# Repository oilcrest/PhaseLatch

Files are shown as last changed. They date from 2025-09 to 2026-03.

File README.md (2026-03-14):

# PhaseLatch

PhaseLatch – 6502-Interfaced High-Speed ADC for Experimental SDR

PhaseLatch is an open-source hardware project that explores how far a classic MOS 6502-class CPU can be pushed into modern signal-processing territory. The board implements a dual-channel, 10-bit, 20 MSPS analog-to-digital converter with a straight binary parallel output, allowing the ADC to be memory-mapped directly onto a 6502 (8 bit) data bus.

Unlike typical SDR designs that rely on high-performance microcontrollers or FPGAs, PhaseLatch intentionally interfaces high-speed conversion hardware with a severely resource-constrained 8-bit CPU. This makes it a platform for experimenting with timing limits, bus contention, memory expansion, and minimalist DSP techniques such as Goertzel tone detection executed entirely on the 6502.

The board is designed as a modular Arduino-shield-style form factor and is intended to stack with the PhaseLoom IQ mixer and the 65uino 6502 system. Direct access to the CPU address, data, and control signals enables single-instruction ADC reads and deterministic sampling under software control.

PhaseLatch is not intended to achieve full theoretical ADC bandwidth on a 6502. Instead, it serves as a practical exploration of real-world limitations, architectural trade-offs, and creative signal-processing approaches on vintage computing hardware.

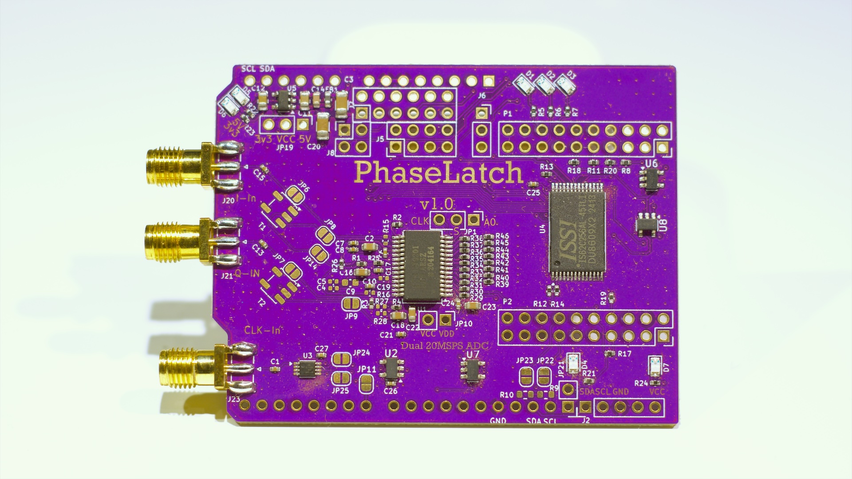
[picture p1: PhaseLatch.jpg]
PhaseLatch board photo


## Purchase

Interested in owning a PhaseLatch?  
[Buy one here](https://www.imania.dk/index.php?cPath=204&sort=5a&language=en).

## How to Use
[6502 source code still lives over on the 65uino project](https://github.com/AndersBNielsen/65uino/)

The main 65uino firmware currently comes with support for the PhaseLatch built in. Time of writing, use the SDR branch. 

To get the full bandwidth out of PhaseLatch, it can also be used with an **FX2LP** USB streaming board instead of the **65uino**.

## Software
The `software/` folder contains the USB streamer firmware + host-side tools for getting PhaseLatch data into SDR software.

- [software/README.md](software/README.md): Overview, build instructions, and a demo cheat sheet.
- [software/firmware/](software/firmware/): FX2/FX2LP firmware (USB streaming).
- [software/host/](software/host/): Host utilities (USB reader, format conversion, DC / IQ correction).
- [software/examples/](software/examples/): Example pipelines (including streaming to `/tmp/iq.fifo` for Gqrx).
- [software/doc/](software/doc/): Notes on wiring and rate planning.

## Using with an FX2LP (USB streaming)
PhaseLatch includes header footprints intended for wiring to an **FX2LP** dev board. The FX2LP provides USB 2.0 high‑speed bulk streaming and acts as the “bridge” from the ADC to a host PC.

At a high level the flow is:
- FX2LP firmware streams raw samples over USB
- host reads via libusb and converts to CF32
- stream is written to `/tmp/iq.fifo` so **Gqrx** can open it

Start with the guide in `software/README.md`, then use `software/examples/pipeline.sh` for a one-command stream to `/tmp/iq.fifo`.

## Getting a PCB

## Production & Manufacturing
- The `jlcpcb/gerber/` folder contains all necessary files for PCB fabrication.
- The `production_files/` folder includes:
  - `BOM-PhaseLatch.csv`: Bill of Materials
  - `CPL-PhaseLatch.csv`: Component Placement List
  - `GERBER-PhaseLatch.zip`: Zipped Gerber files for easy upload

This project is kindly sponsored by JLCPCB. They offer cheap, professional looking PCBs and super fast delivery.

Step 1: Get the gerber file zip package from the /hardware folder

Step 2: Upload to JLCPCB [https://jlcpcb.com/?from=Anders_N](https://jlcpcb.com/?from=Anders_N)

Upload

Step 3: Pick your color, surface finish and order.

Select settings

Save your choice

You can use these affiliate links to get a board for $2 and also get $54 worth of New User Coupons at: https://jlcpcb.com/?from=Anders_N

And in case you also want to order a 3D-printed case you can use this link. 
How to Get a $7 3D Printing Coupon: [https://3d.jlcpcb.com/?from=Anders3DP](https://jlc3dp.com/?from=Anders_N)

---

For more details, technical explanations, and the full story behind PhaseLoom, check out the project video and documentation. Special thanks to JLCPCB and Fnirsi for supporting the development of this project!

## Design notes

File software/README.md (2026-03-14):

# FX2 AD9201 Streamer (16‑bit padded, 512‑byte USB bulk packets)

This project streams 10‑bit samples from an **AD9201** (or similar) into a **Cypress/Infineon EZ‑USB FX2/FX2LP** using an **external IFCLK**, pads them to **16‑bit**, and sends them to the host in **512‑byte** USB bulk packets (the high‑speed bulk max packet size). The host app reads with **libusb** and writes raw bytes to **stdout**, so you can `mkfifo` and pipe into GNU Radio or other tools.

> **Highlights**
> - Firmware: **Slave FIFO + AUTOIN** on **EP6 IN** (512‑byte auto‑commit), **16‑bit bus**, **external IFCLK**.
> - Host: **asynchronous libusb** reader → **stdout** (acts like a FIFO you can pipe from).
> - Wiring: Minimal — data bus, IFCLK, **SLWR** (low for continuous writes), optional FLAGs.

## Why 512‑byte packets?
On **USB 2.0 high‑speed**, the **maximum packet size for bulk endpoints is 512 bytes**. Controllers/OS will split larger transfers into 512‑byte transactions automatically.  
References: Microsoft Learn (USB bulk) and Keil USB bulk docs. 

## FX2 specifics (firmware design)
We configure **IFCONFIG** for **external IFCLK**, **Slave FIFO (IFCFG=01)**, **16‑bit WORDWIDE**, **synchronous** mode, and use **EP6 IN** with **AUTOIN** so the hardware commits 512‑byte packets without 8051 intervention. See the **EZ‑USB FX2 Technical Reference Manual** for register details (IFCONFIG, EPxCFG, EPxAUTOINLEN, EPxFIFOCFG, REVCTL, etc.).  
- EZ‑USB FX2 TRM (Infineon, formerly Cypress): https://www.infineon.com/assets/row/public/documents/24/44/infineon-ez-usb-fx2-trm-version2-2-usermanual-en.pdf

The Cypress getting‑started/Bulkloop flow is a useful sanity check if you need to test USB pipe basics:  
- https://www.manualslib.com/manual/2875994/Cypress-Ez-Usb-Fx2lp.html

## Repository layout
```
fx2-ad9201-streamer/
├── firmware/
│   ├── include/
│   │   └── config.h
│   ├── src/
│   │   └── main.c
│   ├── udev/
│   │   └── 99-fx2.rules
│   └── Makefile
├── host/
│   ├── fx2_stream_stdout.c
│   └── Makefile
├── examples/
│   ├── pipeline.sh
│   └── grc-integration.md
├── tools/
│   └── gpif-notes.md
├── doc/
│   ├── wiring.md
│   └── rate-planning.md
└── LICENSE
```

## Build & Run
### Prereqs
- **Firmware:** SDCC + **fx2lib** headers (`fx2regs.h`, `fx2macros.h`, `syncdelay.h`). Set `FX2LIB` in `firmware/Makefile` to your install path.
- **Host:** libusb‑1.0 dev package (e.g., `sudo apt install libusb-1.0-0-dev`).

### Firmware
```bash
cd firmware
make
# produces build/streamer.ihx
# Load to RAM (choose your tool):
#   fxload  : sudo fxload -t fx2 -I build/streamer.ihx -D /dev/bus/usb/BBB/DDD
#   cycfx2prog: sudo cycfx2prog prg:build/streamer.ihx run
#   Cypress Control Center: Program RAM with .hex/.ihx
```

### Host reader
```bash
cd host
make
mkfifo /tmp/adc.pipe
./fx2_stream_stdout -v 0x04B4 -p 0x8613 -e 0x86 -i 0 -t 16384 -n 32 > /tmp/adc.pipe
```

### GNU Radio quick test
Use a **File Source** reading `/tmp/adc.pipe` with **item size = 2** (u16 or s16 depending on your interpretation; the upper 6 bits are zero). You can re‑interpret to float with a cast/scale block.

See `examples/grc-integration.md` for more options.

## Notes on rates & limits
- Each 512‑byte packet carries **256 samples** at 16‑bit padded.
- Typical sustained USB2 HS bulk throughput is **~40 MB/s** on a good host. Plan your IFCLK accordingly (or decimate in front of FX2).  

## Demo cheat sheet (PhaseLatch → Gqrx)

This is a minimal “copy/paste” workflow to get a live stream into **Gqrx** via the FIFO at `/tmp/iq.fifo`.

### 0) Build host tools
```bash
cd host
make
```

### 1) Create the FIFO (once)
```bash
mkfifo /tmp/iq.fifo
```

### 2) Start streaming to Gqrx (no calibration)
If your raw stream is interleaved unsigned 8‑bit IQ (u8 I,Q), convert to CF32 and write to the FIFO:
```bash
./fx2_stream_stdout -i 0 -t 16384 -n 32 \
	| ./iq_to_cf32 -m 8u \
	> /tmp/iq.fifo
```

### 3) Apply DC correction (run-once calibration, then hardcode)
Measure (run while input is silent):
```bash
./fx2_stream_stdout -i 0 -t 16384 -n 32 \
	| ./iq_dc_cal --samples 65536
```

Then stream with the measured values:
```bash
./fx2_stream_stdout -i 0 -t 16384 -n 32 \
	| ./iq_dc_apply --dcI 3 --dcQ 3 \
	| ./iq_to_cf32 -m 8u \
	> /tmp/iq.fifo
```

### 4) Apply IQ balance (tone calibration, then hardcode)
Tone calibration (example numbers):
```bash
./fx2_stream_stdout -i 0 -t 16384 -n 32 \
	| ./iq_to_cf32 -m 8u \
	| ./iq_iqbal_tone_cal_cf32 --tone-hz 2657000 --fs-hz 20000000 --samples 65536
```

Then stream with correction enabled:
```bash
./fx2_stream_stdout -i 0 -t 16384 -n 32 \
	| ./iq_dc_apply --dcI 3 --dcQ 3 \
	| ./iq_to_cf32 -m 8u \
	| ./iq_iqbal_apply_cf32 --kRe -0.0378 --kIm 0.4850 \
	> /tmp/iq.fifo
```

### Notes
- The writer will block unless **Gqrx is actively reading** `/tmp/iq.fifo`.
- If you want a single command wrapper, see `examples/pipeline.sh`.

## License
MIT (for this repository’s sources).

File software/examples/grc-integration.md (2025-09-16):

# GNU Radio Integration

**Option A: File Source**
1. `mkfifo /tmp/adc.pipe`
2. Run the host reader to fill it.
3. In GRC, add a **File Source**:
   - File: `/tmp/adc.pipe`
   - Repeat: `No`
   - **Item size**: 2 (unsigned/signed short)
4. Convert to float (`UShort to Float` or `Short to Float`) and scale (e.g., `/ 1023.0`).
5. View with a `QT GUI Sink`.

**Option B: TCP bridge**
If you prefer sockets, wrap the host reader stdout with `socat`:
```bash
mkfifo /tmp/adc.pipe
../host/fx2_stream_stdout > /tmp/adc.pipe &
socat -u FILE:/tmp/adc.pipe,ignoreeof TCP-LISTEN:9001,reuseaddr
```
Then use a **TCP Source** in GRC.

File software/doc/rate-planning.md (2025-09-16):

# Rate planning

- **Packetization:** 512 B/packet ⇒ 256 samples/packet at 16‑bit.
- **Throughput:** High‑speed bulk typically sustains ~40 MB/s on a good host/controller; exact numbers vary.
- **Budget:** If you stream both AD9201 channels interleaved at N MSPS each, data rate ≈ `2 * N * 2 B = 4N MB/s`.
  - Example: 4 MSPS/ch ⇒ ~16 MB/s — OK.
  - Example: 10 MSPS/ch ⇒ ~40 MB/s — near practical limit; consider decimation.

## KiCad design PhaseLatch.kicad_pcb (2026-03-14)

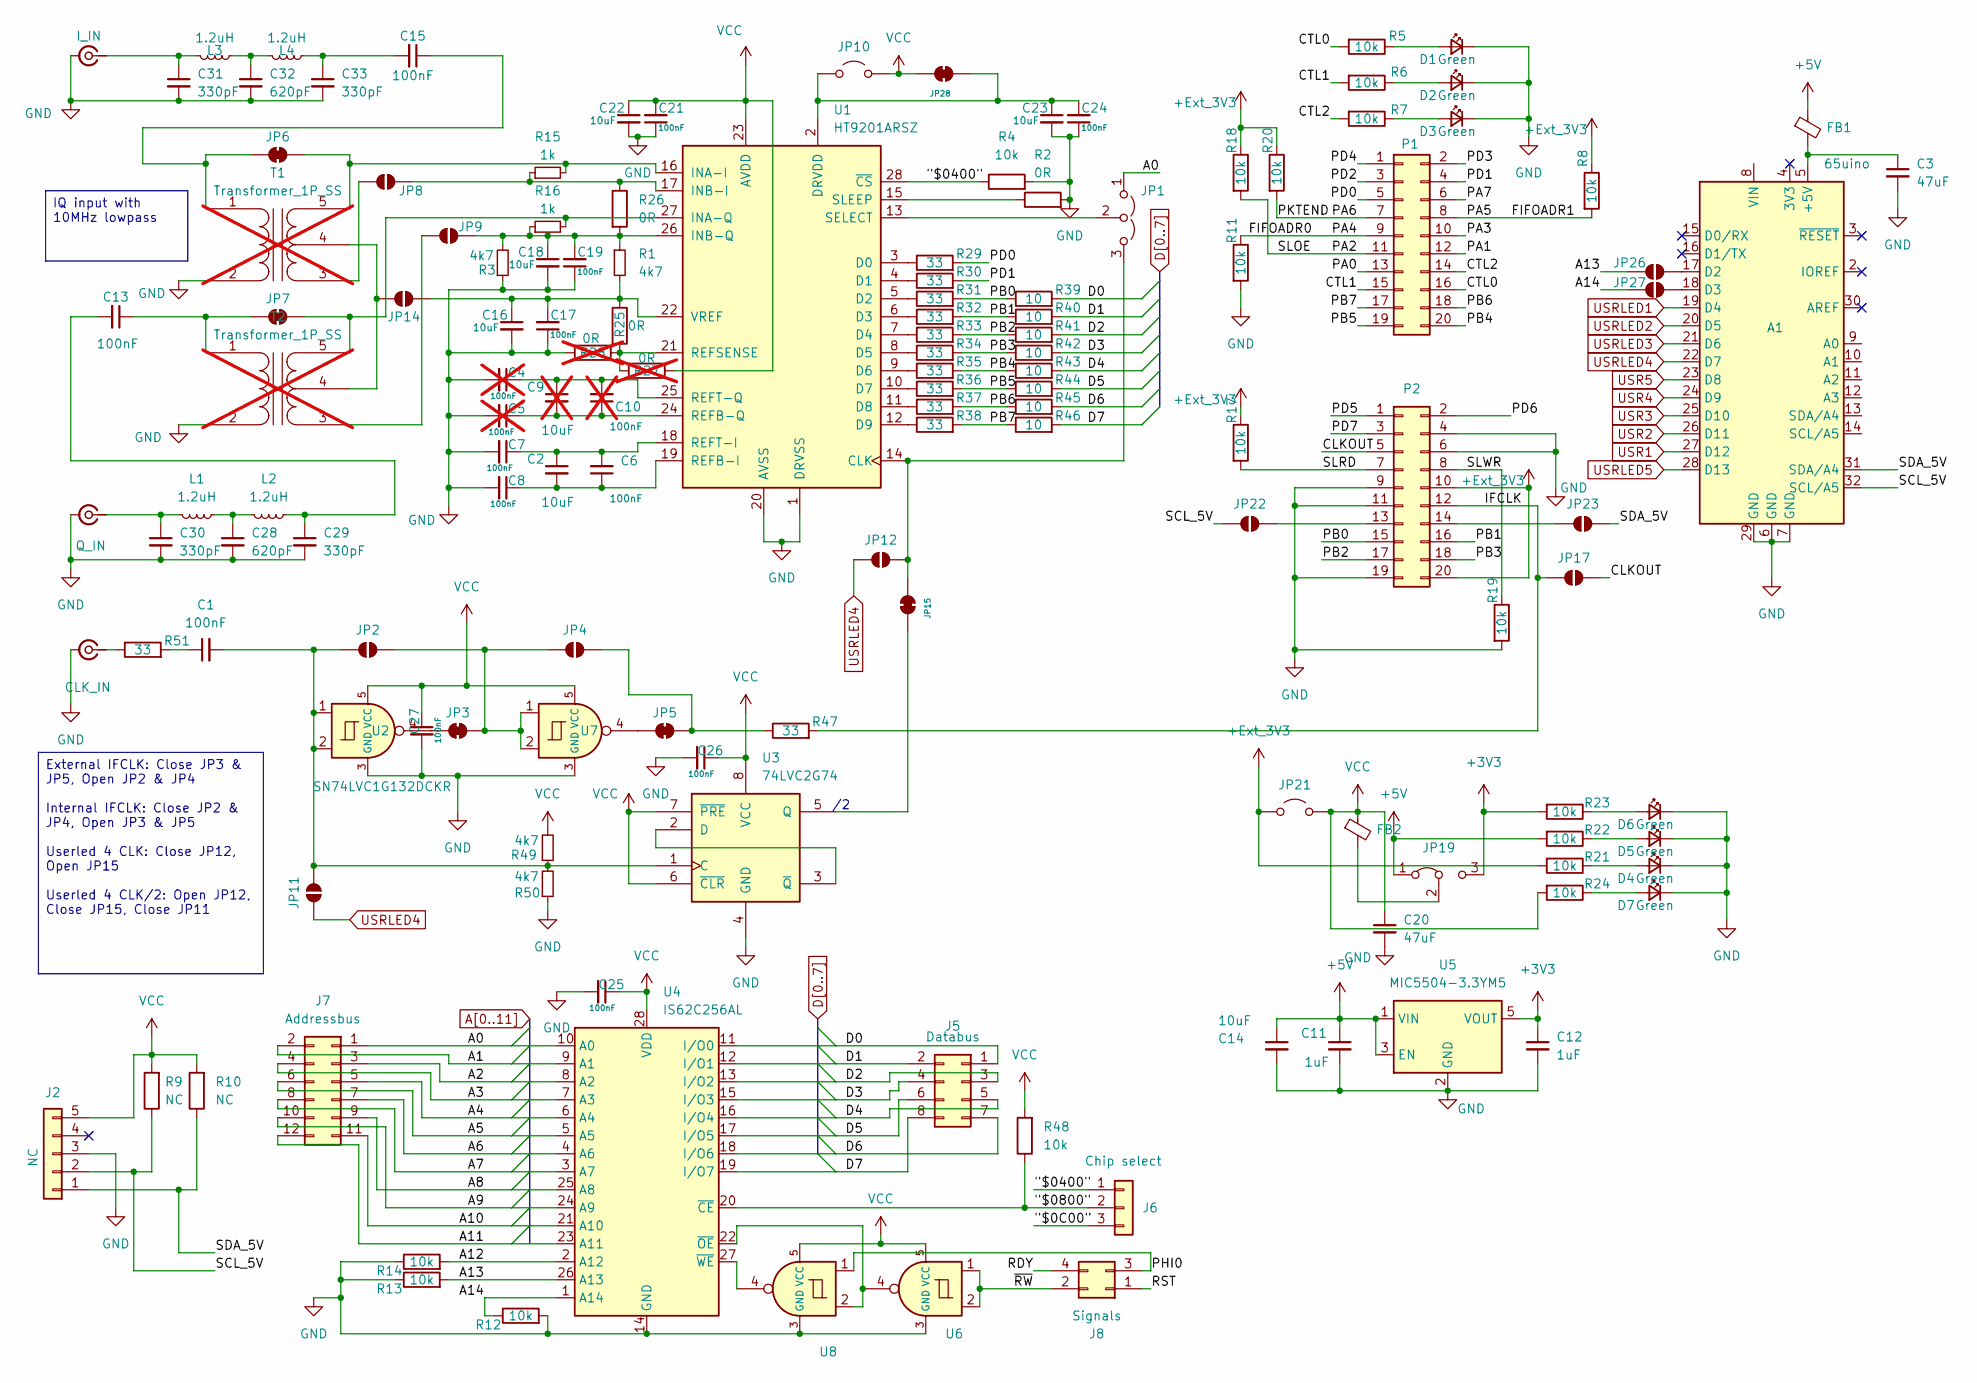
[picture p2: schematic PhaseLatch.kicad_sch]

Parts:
A1: 65uino; Arduino_UNO_R3
C1, C6, C7, C8, C13, C15, C17, C19, C21, C24, C25, C26, C27: 100nF; C_0402_1005Metric; LCSC C1525
C2, C14, C16, C18, C22, C23: 10uF; C_0603_1608Metric; LCSC C96446
C3, C20: 47uF; C_1206_3216Metric; LCSC C96123
C4, C5, C10: 100nF; C_0402_1005Metric; LCSC C1525; not fitted
C9: 10uF; C_0603_1608Metric; LCSC C96446; not fitted
C11, C12: 1uF; C_0805_2012Metric; LCSC C28323
C28, C32: 620pF; C_0402_1005Metric; LCSC C415543
C29, C30, C31, C33: 330pF; C_0402_1005Metric; LCSC C2177105
D1, D2, D3, D4, D5, D6, D7: Green; LED_0805_2012Metric; LCSC C2297
FB1, FB2: FerriteBead_Small; L_0603_1608Metric; LCSC C14709
J2: NC; PinHeader_1x05_P2.54mm_Vertical
J5: Databus; PinHeader_2x04_P2.54mm_Vertical
J6: Chip select; PinSocket_1x03_P2.54mm_Vertical
J7: Addressbus; PinHeader_2x06_P2.54mm_Vertical
J8: Signals; PinHeader_2x02_P2.54mm_Vertical
J20: I_IN; SMA_Samtec_SMA-J-P-H-ST-EM1_EdgeMount; LCSC C5301850
J21: Q_IN; SMA_Samtec_SMA-J-P-H-ST-EM1_EdgeMount; LCSC C5301850
J23: CLK_IN; SMA_Samtec_SMA-J-P-H-ST-EM1_EdgeMount; LCSC C5301850
JP1: Jumper_3_Open; PinHeader_1x03_P2.54mm_Vertical
JP2, JP4, JP8, JP9, JP11, JP12, JP14, JP17, JP22, JP23, JP26, JP27: SolderJumper_2_Open; SolderJumper-2_P1.3mm_Open_RoundedPad1.0x1.5mm
JP3, JP5, JP6, JP7, JP15, JP28: SolderJumper-2_P1.3mm_Bridged_RoundedPad1.0x1.5mm
JP10, JP21: Jumper_2_Open; PinHeader_1x02_P2.54mm_Vertical
JP19: Jumper_3_Bridged12; PinHeader_1x03_P2.54mm_Vertical
L1, L2, L3, L4: 1.2uH; L_0603_1608Metric; LCSC C393979
P1, P2: Conn_02x10_Odd_Even; PinSocket_2x10_P2.54mm_Vertical
R1, R3, R49, R50: 4k7; R_0402_1005Metric; LCSC C25900
R2, R25, R26: 0R; R_0402_1005Metric
R4, R5, R6, R7, R8, R11, R12, R13, R14, R17, R18, R19, R20, R21, R22, R23, R24, R48: 10k; R_0402_1005Metric; LCSC C25744
R9, R10: NC; R_0603_1608Metric
R15, R16: 1k; R_0402_1005Metric; LCSC C11702
R27, R28: 0R; R_0402_1005Metric; not fitted
R29, R30, R31, R32, R33, R34, R35, R36, R37, R38, R47, R51: 33; R_0402_1005Metric; LCSC C25105
R39, R40, R41, R42, R43, R44, R45, R46: 10; R_0402_1005Metric; LCSC C25077
T1, T2: Transformer_1P_SS; Transformer_MiniCircuits_AT224-1A-AltPinout; not fitted
U1: HT9201ARSZ; SSOP-28_5.3x10.2mm_P0.65mm; LCSC C3019546
U2, U6, U7, U8: SN74LVC1G132DCKR; SOT-23-5; LCSC C49188130
U3: 74LVC2G74; VSSOP-8_2.3x2mm_P0.5mm; LCSC C70285
U4: IS62C256AL; TSOP-I-28_11.8x8mm_P0.55mm; LCSC C47143
U5: MIC5504-3.3YM5; SOT-23-5; LCSC C3021093

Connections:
+3V3: C12.1, JP19.3 (B), R23.2, U5.5 (VOUT)
+5V: C11.1, C14.1, FB1.1, JP19.1 (A), R22.2, U5.1 (VIN), U5.3 (EN)
+Ext_3V3: JP21.1 (A), P2.10, P2.20, R8.1, R17.1, R18.1, R20.1, R21.2
/"$0C00": J6.3
/"$0400": J6.1, R4.1, U1.28 (~CS)
/"$0800": J6.2, R48.1, U4.20 (~CE)
/A12: R14.2, U4.2 (A12)
/A13: JP26.1 (A), R13.2, U4.26 (A13)
/A14: JP27.1 (A), R12.1, U4.1 (A14)
/CLKOUT: JP17.2 (B), P2.5
/CTL0: P1.16, R5.2
/CTL1: P1.15, R6.2
/CTL2: P1.14, R7.2
/FIFOADR0: P1.9, R11.1
/FIFOADR1: P1.8, R8.2
/IFCLK: JP17.1 (A), P2.12, R47.2
/PA0: P1.13
/PA1: P1.12
/PA2: P1.11, R18.2
/PA3: P1.10
/PA6: P1.7, R20.2
/PA7: P1.6
/PB0: P2.15, R31.2, R39.1
/PB1: P2.16, R32.2, R40.1
/PB2: P2.17, R33.2, R41.1
/PB3: P2.18, R34.2, R42.1
/PB4: P1.20, R35.2, R43.1
/PB5: P1.19, R36.2, R44.1
/PB6: P1.18, R37.2, R45.1
/PB7: P1.17, R38.2, R46.1
/PD0: P1.5, R29.2
/PD1: P1.4, R30.2
/PD2: P1.3
/PD3: P1.2
/PD4: P1.1
/PD5: P2.1
/PD6: P2.2
/PD7: P2.3
/PHI0: J8.3, U8.1
/RDY: J8.4
/RST: J8.1
/SCL_5V: A1.32 (SCL/A5), J2.2, JP22.1 (A), R9.1
/SDA_5V: A1.31 (SDA/A4), J2.1, JP23.2 (B), R10.1
/SLRD: P2.7, R17.2
/SLWR: P2.8, R19.1
/~RW: J8.2, U6.1, U6.2
A0: J7.1, JP1.1 (A), U4.10 (A0)
A1: J7.2, U4.9 (A1)
A2: J7.3, U4.8 (A2)
A3: J7.4, U4.7 (A3)
A4: J7.5, U4.6 (A4)
A5: J7.6, U4.5 (A5)
A6: J7.7, U4.4 (A6)
A7: J7.8, U4.3 (A7)
A8: J7.9, U4.25 (A8)
A9: J7.10, U4.24 (A9)
A10: J7.11, U4.21 (A10)
A11: J7.12, U4.23 (A11)
D0: J5.1, R39.2, U4.11 (I/O0)
D1: J5.2, R40.2, U4.12 (I/O1)
D2: J5.3, R41.2, U4.13 (I/O2)
D3: J5.4, R42.2, U4.15 (I/O3)
D4: J5.5, R43.2, U4.16 (I/O4)
D5: J5.6, R44.2, U4.17 (I/O5)
D6: J5.7, R45.2, U4.18 (I/O6)
D7: J5.8, R46.2, U4.19 (I/O7)
GND: A1.6 (GND), A1.7 (GND), A1.29 (GND), C3.2, C4.2, C5.2, C7.2, C8.2, C11.2, C12.2, C14.2, C16.2, C17.1, C18.2, C19.1, C20.2, C21.1, C22.2, C23.2, C24.1, C25.2, C26.2, C27.2, C28.2, C29.2, C30.2, C31.2, C32.2, C33.2, D1.1 (K), D2.1 (K), D3.1 (K), D4.1 (K), D5.1 (K), D6.1 (K), D7.1 (K), J2.3, J20.2 (Ext), J21.2 (Ext), J23.2 (Ext), P2.4, P2.6, P2.9, P2.11, P2.19, R2.2, R3.1, R4.2, R11.2, R12.2, R13.1, R14.1, R19.2, R28.1, R50.1, T1.2 (AB), T2.2 (AB), U1.1 (DRVSS), U1.20 (AVSS), U2.3 (GND), U3.4 (GND), U4.14 (GND), U5.2 (GND), U6.3 (GND), U7.3 (GND), U8.3 (GND)
unnamed: A1.5 (+5V), C3.1, FB1.2
unnamed: A1.17 (D2), JP26.2 (B)
unnamed: A1.18 (D3), JP27.2 (B)
unnamed: C1.1, R51.2
unnamed: C13.2, C29.1, L2.1
unnamed: C15.2, C33.1, L4.1
unnamed: C28.1, L1.1, L2.2
unnamed: C32.1, L3.1, L4.2
unnamed: D1.2 (A), R5.1
unnamed: D2.2 (A), R6.1
unnamed: D3.2 (A), R7.1
unnamed: D4.2 (A), R21.1
unnamed: D5.2 (A), R22.1
unnamed: D6.2 (A), R23.1
unnamed: D7.2 (A), R24.1
unnamed: C31.1, J20.1 (In), L3.2
unnamed: C30.1, J21.1 (In), L1.2
unnamed: J23.1 (In), R51.1
unnamed: JP1.3 (B), JP12.2 (B), JP15.2 (B), U1.14 (CLK)
unnamed: JP1.2 (C), U1.13 (SELECT)
unnamed: JP2.2 (B), JP3.2 (B), JP4.1 (A), U7.1, U7.2
unnamed: JP3.1 (A), U2.4
unnamed: JP4.2 (B), JP5.2 (B), R47.1
unnamed: JP5.1 (A), U7.4
unnamed: C15.1, JP6.1 (A), T1.1 (AA)
unnamed: JP6.2 (B), R15.2, T1.5 (SB), U1.16 (INA-I)
unnamed: C13.1, JP7.1 (A), T2.1 (AA)
unnamed: JP7.2 (B), R16.2, T2.5 (SB), U1.27 (INA-Q)
unnamed: JP8.1 (A), R15.1, R26.1, U1.17 (INB-I)
unnamed: JP8.2 (B), T1.3 (SA)
unnamed: C18.1, C19.2, JP9.1 (A), R1.1, R3.2, R16.1, R26.2, U1.26 (INB-Q)
unnamed: JP9.2 (B), T2.3 (SA)
unnamed: C23.1, C24.2, JP10.1 (A), JP28.2 (B), U1.2 (DRVDD)
unnamed: C1.2, JP2.1 (A), JP11.2 (B), R49.1, R50.2, U2.1, U2.2, U3.1 (C)
unnamed: C16.1, C17.2, JP14.1 (A), R1.2, R25.1, U1.22 (VREF)
unnamed: JP14.2 (B), T1.4 (SC), T2.4 (SC)
unnamed: JP15.1 (A), U3.5 (Q)
unnamed: FB2.2, JP19.2 (C)
unnamed: JP22.2 (B), P2.13
unnamed: JP23.1 (A), P2.14
unnamed: R29.1, U1.3 (D0)
unnamed: R30.1, U1.4 (D1)
unnamed: R31.1, U1.5 (D2)
unnamed: R32.1, U1.6 (D3)
unnamed: R33.1, U1.7 (D4)
unnamed: R34.1, U1.8 (D5)
unnamed: R35.1, U1.9 (D6)
unnamed: R36.1, U1.10 (D7)
unnamed: R37.1, U1.11 (D8)
unnamed: R38.1, U1.12 (D9)
unnamed: C2.2, C6.1, C8.1, U1.19 (REFB-I)
unnamed: C5.1, C9.2, C10.1, U1.24 (REFB-Q)
unnamed: R25.2, R27.1, R28.2, U1.21 (REFSENSE)
unnamed: C2.1, C6.2, C7.1, U1.18 (REFT-I)
unnamed: C4.1, C9.1, C10.2, U1.25 (REFT-Q)
unnamed: R2.1, U1.15 (SLEEP)
unnamed: U3.2 (D), U3.3 (~Q)
unnamed: U4.22 (~OE), U6.4, U8.2
unnamed: U4.27 (~WE), U8.4
USR1: A1.27 (D12)
USR2: A1.26 (D11)
USR3: A1.25 (D10)
USR4: A1.24 (D9)
USR5: A1.23 (D8)
USRLED1: A1.19 (D4)
USRLED2: A1.20 (D5)
USRLED3: A1.21 (D6)
USRLED4: A1.22 (D7), JP11.1 (A), JP12.1 (A)
USRLED5: A1.28 (D13)
VCC: C20.1, C21.2, C22.1, C25.1, C26.1, C27.1, FB2.1, J2.5, JP10.2 (B), JP21.2 (B), JP28.1 (A), R9.2, R10.2, R24.2, R27.2, R48.2, R49.2, U1.23 (AVDD), U2.5 (VCC), U3.6 (~CLR), U3.7 (~PRE), U3.8 (VCC), U4.28 (VDD), U6.5 (VCC), U7.5 (VCC), U8.5 (VCC)

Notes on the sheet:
IQ input with 10MHz lowpass
External IFCLK: Close JP3 & JP5, Open JP2 & JP4 Internal IFCLK: Close JP2 & JP4, Open JP3 & JP5 Userled 4 CLK: Close JP12, Open JP15 Userled 4 CLK/2: Open JP12, Close JP15, Close JP11

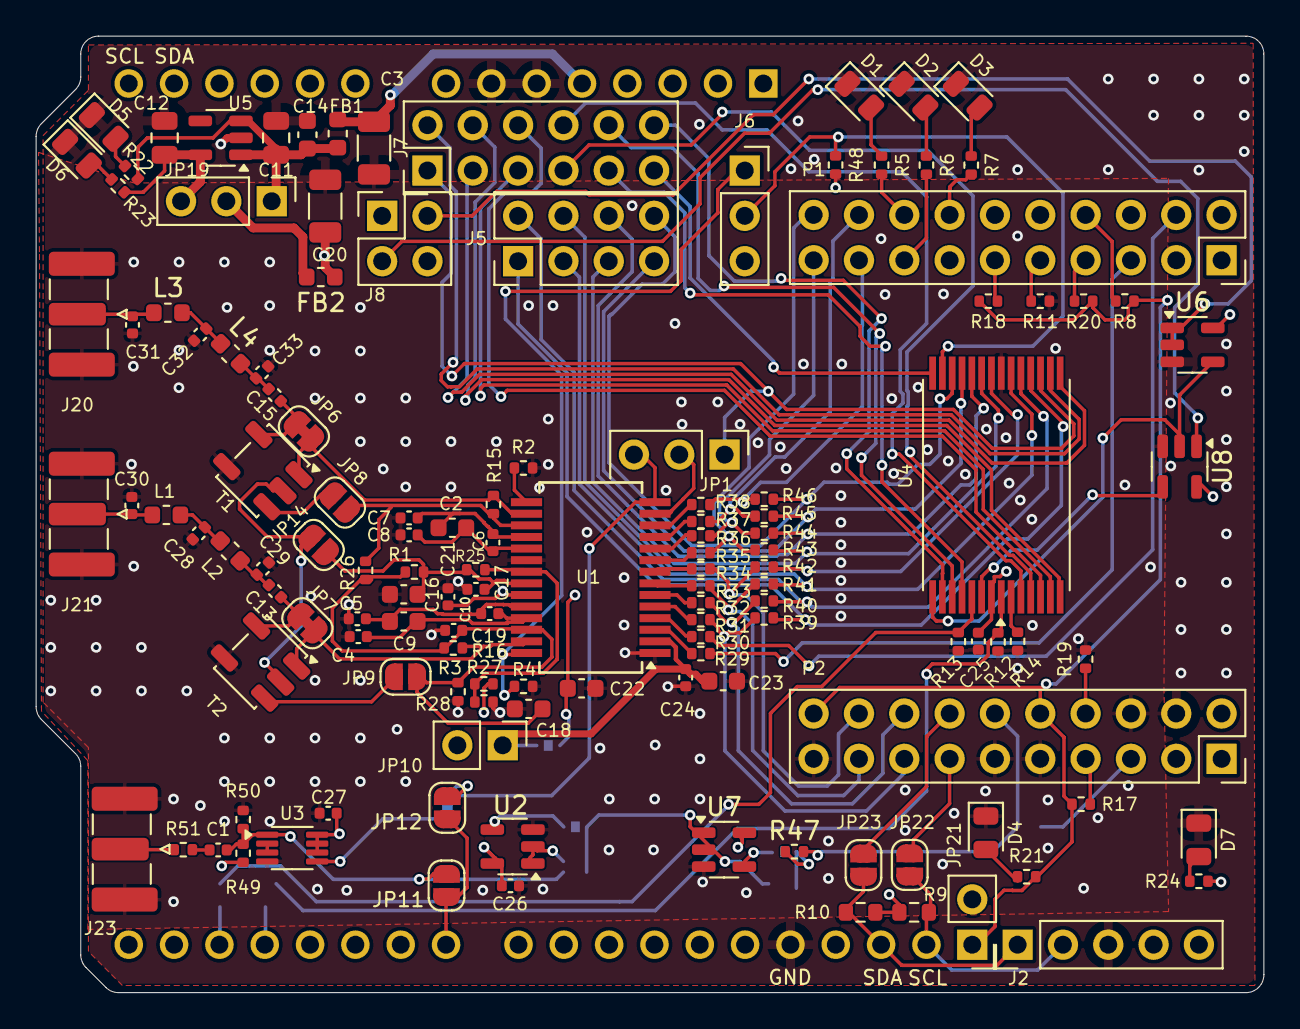
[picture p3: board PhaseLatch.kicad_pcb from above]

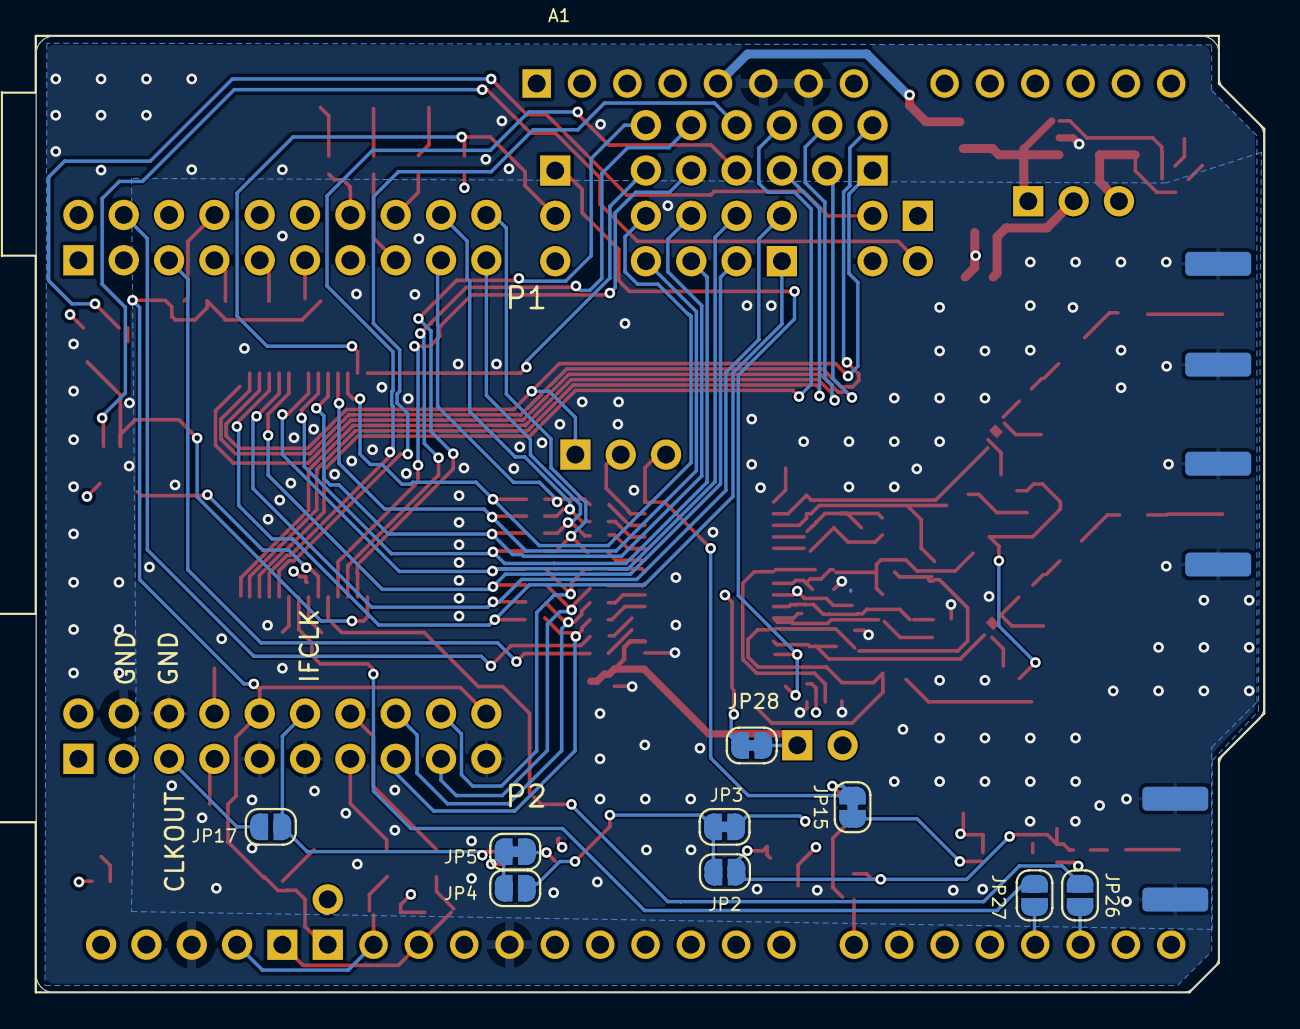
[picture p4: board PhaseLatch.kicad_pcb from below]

Board: 4 copper layers, 68.8 x 53.6 mm, 140 parts (10 on the bottom side), 115 nets.

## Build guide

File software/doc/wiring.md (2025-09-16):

# Wiring (AD9201 → FX2 in Slave FIFO mode)

**Clocks**
- `IFCLK` (from your ADC sampling clock) → FX2 `IFCLK` pin (external clock). Use the rate you need.

**Data**
- FX2 `D[15:10]` = tie to `0` (or use for Q if you interleave differently)
- FX2 `D[9:0]`   = `AD9201[9:0]` (one channel). If using both I/Q channels at once, interleave externally and map into 16‑bit words.

**Control**
- `SLWR`   → **tie low** for continuous write on each IFCLK edge (simplest). Alternatively, drive from a CPLD/FPGA per sample.
- `PKTEND` → tie high (unused; AUTOIN commits every 512 B).
- `SLRD`/`SLOE` → tie high (unused; we don’t read from FX2).
- Optional `FLAGB/FLAGC` → monitor FIFO status if you implement flow control.

> Ensure setup/hold relative to IFCLK meets FX2 timing (TRM timing tables). If running close to USB limits, consider an FPGA shim to safely time‑align and optionally decimate.

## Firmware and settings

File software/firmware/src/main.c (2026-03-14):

// FX2 firmware: Internal IFCLK + Slave FIFO + AUTOIN (EP6 IN, 512 B)
// Build: SDCC + fx2lib headers

#include <fx2regs.h>
#include <fx2macros.h>
#include <syncdelay.h>
#include "config.h"
#include "fx2_helpers.h"
#include <setupdat.h>

// Uncomment to enable internal firmware pattern generator test (bypasses external producer)
//#define PATTERN_TEST 1

#define SD() SYNCDELAY; SYNCDELAY;

// ---------------- Vendor command support -----------------
// We preserve your original CPUCS bit comments EXACTLY as provided below.

// Simple vendor protocol (control endpoint):
//  OUT (Host->Device) commands expect 2 bytes: MASK, VALUE. Bits where MASK=1 are replaced.
//  IN  (Device->Host) commands return 1 byte.
//  Codes (avoid 0xA0–0xAF reserved by EZ-USB):
//    0xB0: SET CPUCS
//    0xB1: GET CPUCS
//    0xB2: SET IFCONFIG
//    0xB3: GET IFCONFIG
//    0xB4: SET PORTA (IOA)
//    0xB5: GET PORTA (IOA)
//    0xB6: SET OEA
//    0xB7: GET OEA
//    0xB8: GET EP6CS
//    0xB9: GET PINFLAGSAB
//    0xBA: GET PINFLAGSCD
//    0xBB: GET IFCONFIG snapshot (captured right after firmware init)

// Use the shared helper macro for masked writes
// FX2_MASKED_WRITE(reg, mask, value)

// Handle vendor commands (called by fx2lib's handle_setupdata flow)
// fx2lib will call this for vendor commands (weak symbol override)
BOOL handle_vendorcommand(BYTE cmd) {
    switch(cmd) {
        case 0xB0: // SET CPUCS
        case 0xB2: // SET IFCONFIG
        case 0xB4: // SET PORTA
        case 0xB6: // SET OEA
        {
            // Expect 2 OUT bytes
            if(EP0BCL != 2) return FALSE; // not enough data yet
            BYTE mask = EP0BUF[0];
            BYTE val  = EP0BUF[1];
                if(cmd == 0xB0) FX2_MASKED_WRITE(CPUCS, mask, val);
                else if(cmd == 0xB2) FX2_MASKED_WRITE(IFCONFIG, mask, val);
                else if(cmd == 0xB4) FX2_MASKED_WRITE(IOA, mask, val);
                else FX2_MASKED_WRITE(OEA, mask, val);
            return TRUE;
        }
            case 0xB1: // GET CPUCS
            EP0BUF[0] = CPUCS; EP0BCL = 1; return TRUE;
            case 0xB3: // GET IFCONFIG
            EP0BUF[0] = IFCONFIG; EP0BCL = 1; return TRUE;
            case 0xB5: // GET PORTA
            EP0BUF[0] = IOA; EP0BCL = 1; return TRUE;
            case 0xB7: // GET OEA
            EP0BUF[0] = OEA; EP0BCL = 1; return TRUE;
            case 0xB8: // GET EP6CS (FIFO status)
                EP0BUF[0] = EP6CS; SD(); EP0BCL = 1; SD(); return TRUE;
            case 0xB9: // GET PINFLAGSAB
                EP0BUF[0] = PINFLAGSAB; SD(); EP0BCL = 1; SD(); return TRUE;
            case 0xBA: // GET PINFLAGSCD
                EP0BUF[0] = PINFLAGSCD; SD(); EP0BCL = 1; SD(); return TRUE;
            case 0xBB: // GET IFCONFIG snapshot
                extern BYTE boot_ifconfig_snapshot;
                EP0BUF[0] = boot_ifconfig_snapshot; SD(); EP0BCL = 1; SD(); return TRUE;
    }
    return FALSE; // not handled
}

// Optional simple pattern generator for AUTOIN endpoint 6 (16-bit wide)
#ifdef PATTERN_TEST
static void push_pattern_ep6(void) {
    // Fill exactly AUTOIN_LEN bytes. We assume AUTOIN length = 512 (set below)
    // Write 16-bit words incrementing.
    static WORD w = 0;
    BYTE __xdata *p = (BYTE __xdata*) &EP6FIFOBUF; // fx2lib symbol
    WORD count = 0;
    while(count < 512) {
        p[count++] = (BYTE)(w & 0xFF);
        p[count++] = (BYTE)((w >> 8) & 0xFF);
        ++w;
    }
    // Arm packet if manual commit needed (AUTOIN handles length threshold auto-commit)
}
#endif

// Snapshot of IFCONFIG captured during init
BYTE boot_ifconfig_snapshot = 0x00;

void main(void) {
    //Bits
    //7-6: Reserved
    //5: PortCSTB
    //4-3: 00 = 12MHz, 01 = 24MHz, 10 = 48MHz, 11 = Reserved
    //2: CLKINV 
    //1: CLKOE
    //0 - reserved
    CPUCS = 0x0A;  SD(); // 24 MHz, CLKOUT enabled

    IFCONFIG = IFCONFIG_VALUE;  SYNCDELAY;
    // Capture IFCONFIG immediately after we set it
    {
        extern BYTE boot_ifconfig_snapshot;
        boot_ifconfig_snapshot = IFCONFIG;
    }
    REVCTL = 0x03;    SYNCDELAY;  // Enhanced Packet Handling (TRM recommendation for slave FIFO)

    // Configure EP6 (IN) for bulk input, quad-buffered (4*512 bytes).
    EP6CFG = 0xE0;  SYNCDELAY; // 1110 0000: VALID + IN + BULK + Quad

    // FIFO Reset sequence (TRM)
    FIFORESET = 0x80;  SYNCDELAY;  // NAK all requests
    FIFORESET = 0x82;  SYNCDELAY;  // Reset EP2
    FIFORESET = 0x84;  SYNCDELAY;  // Reset EP4
    FIFORESET = 0x86;  SYNCDELAY;  // Reset EP6
    FIFORESET = 0x88;  SYNCDELAY;  // Reset EP8
    FIFORESET = 0x00;  SYNCDELAY;  // Release NAKs

    // Configure EP6 for AUTOIN, 16bit wide bus. Bits: 0000 1110 ( AUTOIN=1 / ZEROLENIN=1, Wordwide=1 )
    EP6FIFOCFG = 0x0C;  SYNCDELAY;

    // PORTACFG: FLAGD SLCS(*) 0 0 0 0 INT1 INT0
    PORTACFG = 0x00;  SYNCDELAY;

    // All default polarities: SLWR active low, etc.
    FIFOPINPOLAR=0x00;  SYNCDELAY;

    // AUTOIN packet commit length (512 bytes)
    EP6AUTOINLENH = 0x02; SYNCDELAY;  // MSB
    EP6AUTOINLENL = 0x00; SYNCDELAY;  // LSB

    PINFLAGSAB = 0x00; SYNCDELAY; // No special flags on Port A/B pins  
    PINFLAGSCD = 0x00; SYNCDELAY; // No special flags on Port C/D pins

    // LED on PA0 for heartbeat
    OEA |= 0x01; // PA0 output

    // Main superloop: blink + optional pattern fill (control transfers handled by fx2lib core)
    unsigned long blink = 0UL;
    for(;;) {
        // Poll for setup data so vendor commands are handled
        handle_setupdata();
        if(++blink == 40000UL) { PA0 = 1; }
        else if(blink == 80000UL) { PA0 = 0; blink = 0UL; }
#ifdef PATTERN_TEST
        if(!(EP6CS & 0x02)) { // 0x02 == FULL bit
            push_pattern_ep6();
        }
#endif
    }
}

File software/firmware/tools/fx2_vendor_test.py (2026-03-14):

#!/usr/bin/env python3
"""
Simple PyUSB vendor-control test for FX2 firmware.

Uses firmware vendor commands in the 0xB0–0xBA range:
- 0xB1: GET CPUCS
- 0xB0: SET CPUCS (masked write: [mask, value])
- 0xB3: GET IFCONFIG
- 0xB8: GET EP6CS
- 0xB9: GET PINFLAGSAB
- 0xBA: GET PINFLAGSCD
"""
import sys
import usb.core
import usb.util
from usb.core import USBTimeoutError

VID = 0x04B4
PID = 0x8613

dev = usb.core.find(idVendor=VID, idProduct=PID)
if dev is None:
    raise SystemExit("FX2 device not found; ensure firmware is flashed and device is powered")

print('Found device: idVendor=0x%04x idProduct=0x%04x' % (VID, PID))
print('Device object:', dev)

# Try to set configuration
try:
    dev.set_configuration()
    print('Set configuration OK')
except Exception as e:
    print('set_configuration:', repr(e))

# Attempt to detach kernel driver (if any) and claim interface 0
cfg = None
try:
    cfg = dev.get_active_configuration()
    print('Active configuration:', cfg.bConfigurationValue)
    intf = cfg[(0, 0)]
    print('Found interface:', intf.bInterfaceNumber)
    if dev.is_kernel_driver_active(intf.bInterfaceNumber):
        try:
            dev.detach_kernel_driver(intf.bInterfaceNumber)
            print('Detached kernel driver from interface', intf.bInterfaceNumber)
        except Exception as e:
            print('Failed to detach kernel driver:', e)
    try:
        usb.util.claim_interface(dev, intf.bInterfaceNumber)
        print('Claimed interface', intf.bInterfaceNumber)
    except Exception as e:
        print('claim_interface failed (may be OK on macOS):', e)
except Exception as e:
    print('Could not get/claim interface info:', e)

def try_ctrl_transfer(request_type_list, request, data_or_length, timeout=5000):
    """Try a list of bmRequestType values until one succeeds."""
    last_exc = None
    for rt in request_type_list:
        try:
            if isinstance(data_or_length, int):
                d = dev.ctrl_transfer(rt, request, 0, 0, data_or_length, timeout=timeout)
            else:
                d = dev.ctrl_transfer(rt, request, 0, 0, data_or_length, timeout=timeout)
            return rt, d
        except Exception as e:
            last_exc = e
    raise last_exc

def get_byte(request, timeout=5000):
    """Generic GET for one byte from firmware via vendor IN request code."""
    rts = [0xC0, 0xC1, 0xC2]
    rt, data = try_ctrl_transfer(rts, request, 1, timeout=timeout)
    print('GET 0x%02x succeeded with bmRequestType=0x%02x' % (request, rt))
    return int(data[0])

def get_cpucs(timeout=5000):
    return get_byte(0xB1, timeout)

def get_ifconfig(timeout=5000):
    return get_byte(0xB3, timeout)

def get_ep6cs(timeout=5000):
    return get_byte(0xB8, timeout)

def get_pinflags_ab(timeout=5000):
    return get_byte(0xB9, timeout)

def get_pinflags_cd(timeout=5000):
    return get_byte(0xBA, timeout)

def get_ifconfig_snapshot(timeout=5000):
    return get_byte(0xBB, timeout)

try:
    print('CPUCS before:', hex(get_cpucs()))
except USBTimeoutError as e:
    print('Timeout reading CPUCS (no response). Is firmware running and handling vendor requests?')
    print('Error:', e)
    sys.exit(2)

def set_cpucs_masked(mask, value, timeout=5000):
    """Masked write to CPUCS via vendor OUT 0xB0: payload [mask, value]."""
    rts_out = [0x40, 0x41, 0x42]
    rt_out, _ = try_ctrl_transfer(rts_out, 0xB0, [mask & 0xFF, value & 0xFF], timeout=timeout)
    print('SET CPUCS masked (mask=0x%02x, value=0x%02x) via bmRequestType=0x%02x' % (mask, value, rt_out))

def set_ifconfig_masked(mask, value, timeout=5000):
    """Masked write to IFCONFIG via vendor OUT 0xB2: payload [mask, value]."""
    rts_out = [0x40, 0x41, 0x42]
    rt_out, _ = try_ctrl_transfer(rts_out, 0xB2, [mask & 0xFF, value & 0xFF], timeout=timeout)
    print('SET IFCONFIG masked (mask=0x%02x, value=0x%02x) via bmRequestType=0x%02x' % (mask, value, rt_out))

# Read diagnostics first to avoid aborting on CPUCS errors
try:
    print('IFCONFIG:', hex(get_ifconfig()))
    print('IFCONFIG snapshot (boot):', hex(get_ifconfig_snapshot()))
except Exception as e:
    print('Diagnostics GET failed (IFCONFIG):', e)

# Try toggling CLKOE (bit1), but continue on failure
try:
    before = get_cpucs()
    print('CPUCS before:', hex(before))
    set_cpucs_masked(0x02, before ^ 0x02)
    after = get_cpucs()
    print('CPUCS after toggle bit1:', hex(after))
except Exception as e:
    print('CPUCS SET failed:', e)

# Restore: read original and clear bit
orig = get_cpucs()
try:
    set_cpucs_masked(0x02, orig & ~0x02)
    print('Restored CPUCS to:', hex(get_cpucs()))
except Exception as e:
    print('Failed to restore CPUCS:', e)

try:
    # Try forcing IFCONFIG to 0xE3 and read back, but continue on failure
    try:
        set_ifconfig_masked(0xFF, 0xE3)
        print('IFCONFIG after set 0xE3:', hex(get_ifconfig()))
    except Exception as e:
        print('IFCONFIG SET failed:', e)
    print('EP6CS   :', hex(get_ep6cs()))
    print('PINFLAGSAB:', hex(get_pinflags_ab()))
    print('PINFLAGSCD:', hex(get_pinflags_cd()))
except Exception as e:
    print('Diagnostics GET failed (EP/flags):', e)

print('Vendor control test completed successfully')

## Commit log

2025-09-17 Series termination, fork resistors
    [PhaseLatch.kicad_pcb, PhaseLatch.kicad_sch]
2026-03-14 IQ bias offset, IQ balancing, documentation
    [PhaseLatch.kicad_pcb, PhaseLatch.kicad_sch]
